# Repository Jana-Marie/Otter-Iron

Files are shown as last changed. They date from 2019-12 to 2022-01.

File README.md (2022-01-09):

# Otter-Iron

Replacement PCB for TS100, adds USB-C PD to every hacker's favourite tool!

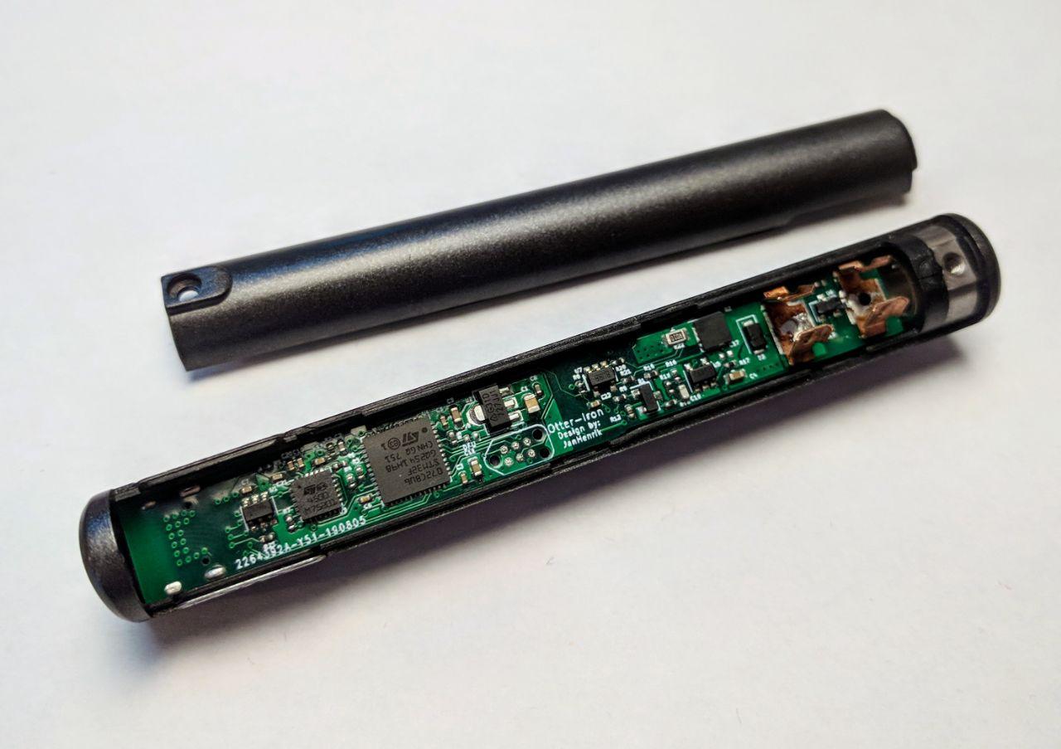
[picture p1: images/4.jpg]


Hardware v2.4 is released, changelog: you don't need to solder the tip connector anymore, software [v0.6](https://github.com/Jana-Marie/Otter-Iron/releases) is released!

Features:
 - You can solder!
 - Temperature can be adjusted via buttons
 - USB-PD requests highest voltage
 - Display shows set-temperature, temperature, input-voltage and power applied
 - Saves last set-temperature
 - Designed by an Otter *chirps* :3

## Ordering and assembly instructions

The BOM can be found at [KiCAD/Otter-Iron/production/kitspace_bom.csv](./KiCAD/Otter-Iron/production/kitspace_bom.csv). Most parts are generic parts, which can be ordered and assembled regularly. However, the display and tip-holders need special attention. The PCB has to be ordered with a thickness of 1mm (1.6mm works too, but 1mm has a better fit).

### Known hardware issues/notes

 * **Note: C19 and C20 changed from 100nF to 1µF in the last revision, please make sure to populate 1µF!**
 * Please add a pullup to the displays reset if the display does not work. See image below:

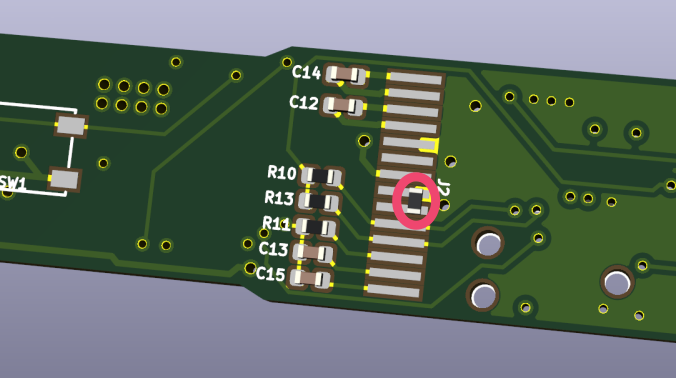
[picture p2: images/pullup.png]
 

### Tip-Holders / mechanical parts

The original tip-holders are custom made thus it is not possible to buy them, if you already have a TS100 it is highly recommended to recycle those. They can be unscrewed, cut to size and soldered/screwed onto the Otter-Iron. This is the preferred option!

If you don't own a TS100 you can buy one from miniware (price ranges from 35$ to 45$) and harvest the parts (as well as the casing and tip!).

You can also buy the littlefuse fuseholders mentioned in the BOM. Those however have a very bad fit, you have to bend them and add a little solder notch, otherwise you may destroy your tips. In addition to this solution you also need to buy a spare case+tip which is ~25-35$, this is the least preferred option.

### Display

The display can be bought from ~~[LCSC](https://lcsc.com/product-detail/OLED-Displays-Modules_UG-Univision-Semicon-UG-9616TSWCG02_C88335.html)~~ **note: Do not buy displays from LCSC, they seem to be faulty!** or [Aliexpress](https://de.aliexpress.com/item/32808645444.html), I haven't found it at Mouser yet ([Maybe its this display?](https://www.mouser.de/ProductDetail/ELECTRONIC-ASSEMBLY/EA-W096016-XALW?qs=f9yNj16SXrJLTMk24BHqcA%3D%3D)). It is the last part to be assembled, it is soldered on the back of the PCB facing the PCB and the tip-end.

## Flashing

To flash the Otter-Iron short the DFU-jumper shown in the image below while plugging it into your computer. This will put the iron into DFU mode allowing you to flash it via DFU/USB.

If you already have ad firmware >= v0.2 flashed, you can press both buttons while plugging in to enter DFU mode.

Run this command to flash the downloaded binary.

    $ dfu-util -a 0 -s 0x08000000:leave -D firmware.bin

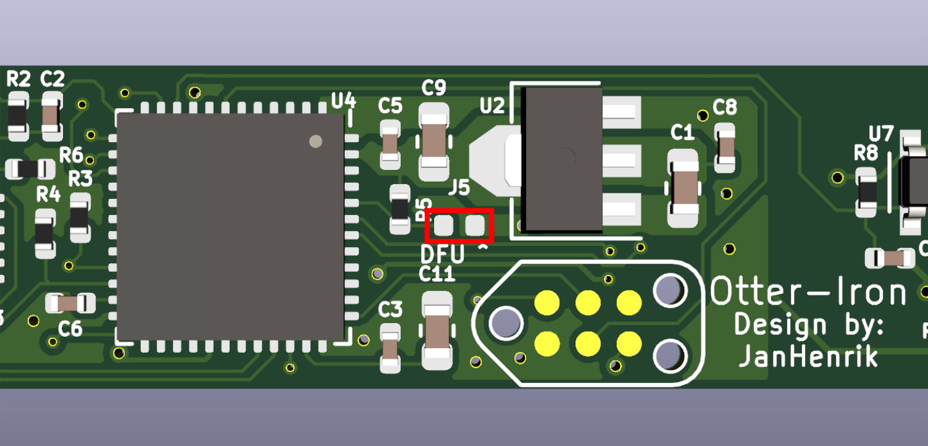
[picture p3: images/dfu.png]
dfu


## Video

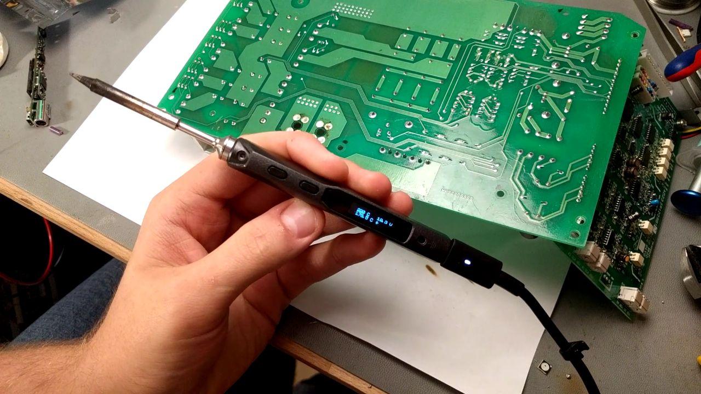
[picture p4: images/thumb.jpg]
Video (https://twitter.com/_Jana_Marie/status/1208867279540232192)


## Images

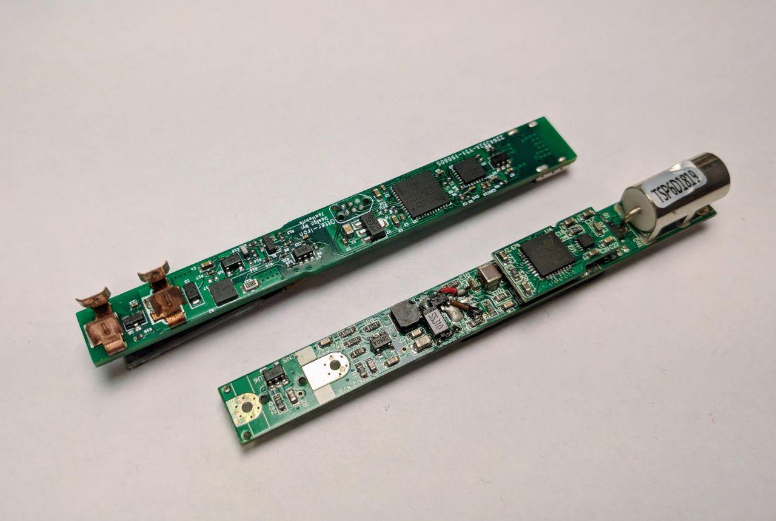
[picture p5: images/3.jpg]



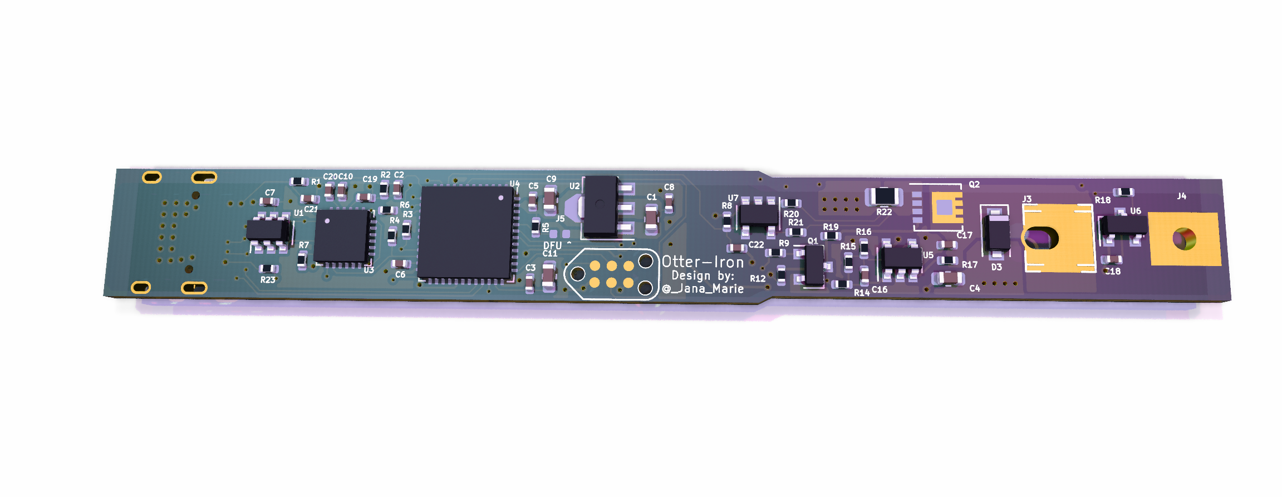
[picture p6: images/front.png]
Front

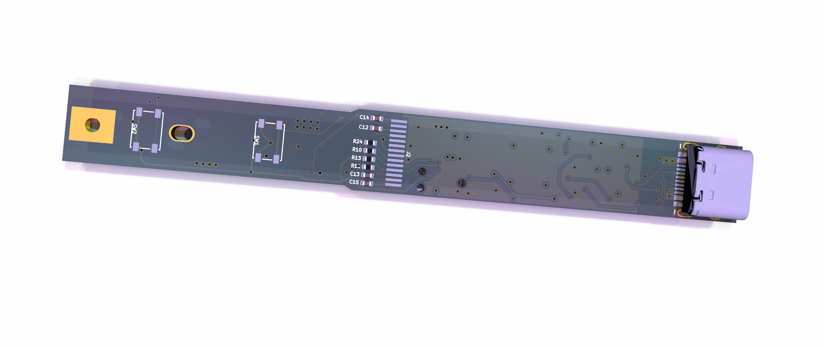
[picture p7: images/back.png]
Back


## Todo software

 - [x] Write a better regulation
 - [x] Current measurement
 - [x] Store last setpoint
 - [x] Better Fonts/UI
 - [x] PD-Profile cycling

## Todo Hardware

Todo next hardware revision:
 - [ ] Add barrel jack
 - [ ] Add grounding solution
 - [x] Fix Tag-Connect [see #4](https://github.com/Jana-Marie/Otter-Iron/issues/4)
 - [x] Optimize display-connector
 - [x] Add display reset pullup
 - [ ] Add display reset line
 - [ ] Add inrush current protection

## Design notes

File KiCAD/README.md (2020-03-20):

# Folder structure

## Otter-Iron

Replacement PCB for the TS100.



## Otter-Iron_Devkit

Small devboard based on the Otter-Iron for different tips (e.g. Weller RT, JBC C245)

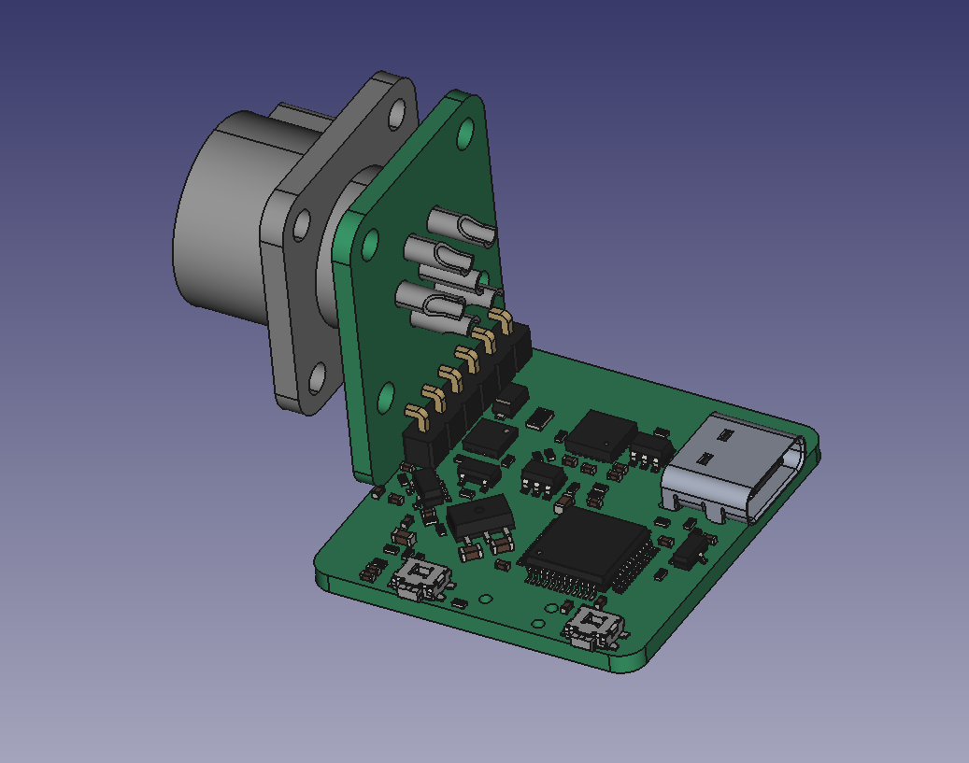
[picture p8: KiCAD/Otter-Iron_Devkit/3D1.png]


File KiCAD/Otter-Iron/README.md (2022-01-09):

[BOM](KiCAD/production/kitspace_bom.csv)

[Gerber](KiCAD/production/TS100CV2.3.zip)

[Kitspace](https://kitspace.org/boards/github.com/jana-marie/otter-iron/)

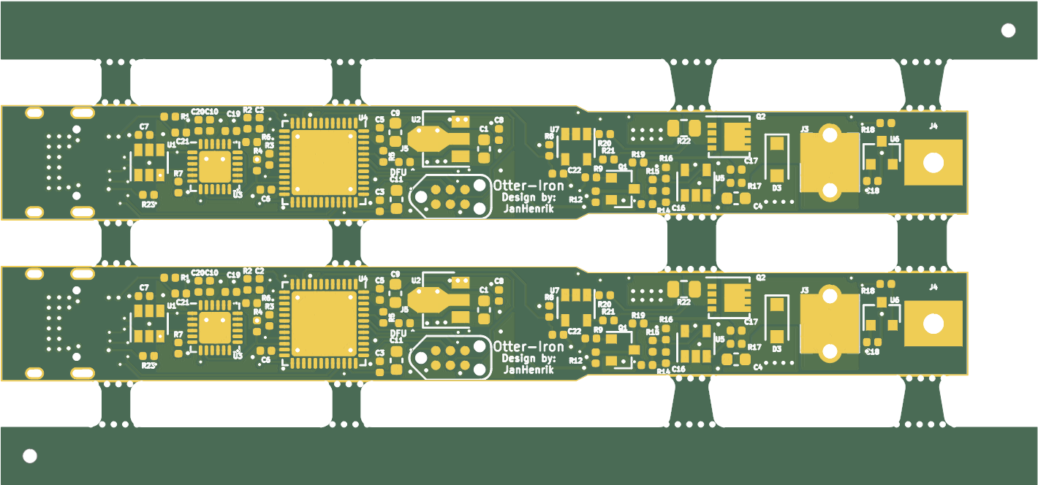
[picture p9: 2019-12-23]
KiCAD/Otter-Iron/production/v2.3_Combined_Top.png

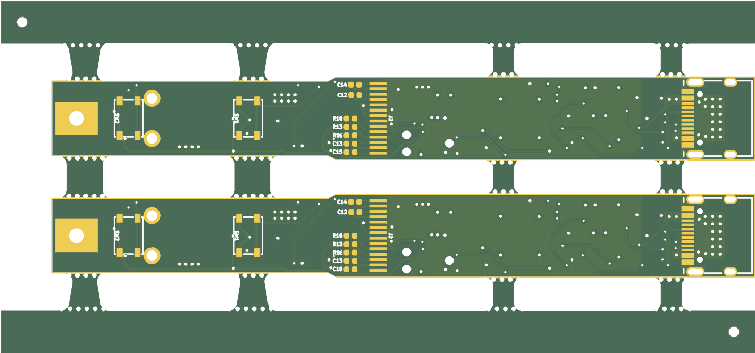
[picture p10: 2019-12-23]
KiCAD/Otter-Iron/production/v2.3_Combined_Bottom.png

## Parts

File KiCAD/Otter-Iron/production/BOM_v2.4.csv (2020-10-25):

Comment | Designator | Quantity | Footprint | LCSC | LCSC Part type | Mouser | Farnell
1μF 25V | C15,C13,C14,C12,C20,C19 | 6 | Capacitor_SMD:C_0402_1005Metric | C52923 | smt
18p | C16 | 1 | Capacitor_SMD:C_0402_1005Metric | C1549 | smt
DNP | C17 | 1 | Capacitor_SMD:C_0402_1005Metric | DNP | dnp
0.1μF | C3,C5,C7,C8,C10,C2,C18,C6,C21,C22 | 10 | Capacitor_SMD:C_0402_1005Metric | C1525 | smt
1μF 25V | C9,C1,C4,C11 | 4 | Capacitor_SMD:C_0603_1608Metric | C15849 | smt
B140-E3 | D3 | 1 | Diode_SMD:D_SOD-123F | C64891 | ext
USB_C_Receptacle_USB2.0 | J1 | 1 | otter:USB-C 16Pin | C319148 | lcsc
OLED_96x16 | J2 | 1 | otter:0.69OLED
A | J3 | 1 | otter:Keystone_3621 |  |  | 534-3621
B | J4 | 1 | otter:Keystone_3622 |  |  | 534-3622
DNP | J5 | 1 | Resistor_SMD:R_0402_1005Metric | DNP | dnp
SS8050 | Q1 | 1 | Package_TO_SOT_SMD:SOT-23 | C2150 | smt
DMP3017SFG | Q2 | 1 | otter:Diodes_PowerDI3333-8 | C461072 | lcsc
560k | R1,R11 | 2 | Resistor_SMD:R_0402_1005Metric | C132339 | ext
750k | R15 | 1 | Resistor_SMD:R_0402_1005Metric | C122545 | ext
20 | R19 | 1 | Resistor_SMD:R_0402_1005Metric | C25089 | ext
100k | R2,R17 | 2 | Resistor_SMD:R_0402_1005Metric | C25741 | smt
33 | R20,R21 | 2 | Resistor_SMD:R_0402_1005Metric | C25105 | smt
10m | R22 | 1 | Resistor_SMD:R_0805_2012Metric | C50732 | ext
2k37 | R5,R3,R4,R6,R12,R9,R10,R13,R16,R14,R18,R7,R8,R23 | 14 | Resistor_SMD:R_0402_1005Metric | C25881 | ext
key1 | SW1 | 1 | Button_Switch_SMD:SW_SPST_PTS810 | C92589 | lcsc
key2 | SW2 | 1 | Button_Switch_SMD:SW_SPST_PTS810 | C92589 | lcsc
USBLC6-4SC6 | U1 | 1 | Package_TO_SOT_SMD:SOT-23-6 | C111212 | ext |  | 1295311
AP2204R-3.3 | U2 | 1 | Package_TO_SOT_SMD:SOT-89-3 | C156303 | ext
STUSB4500QTR | U3 | 1 | Package_DFN_QFN:QFN-24-1EP_4x4mm_P0.5mm_EP2.7x2.7mm |  |  | 511-STUSB4500QTR | 2980889
STM32F072CBUx | U4 | 1 | Package_DFN_QFN:QFN-48-1EP_7x7mm_P0.5mm_EP5.6x5.6mm | C92504 | ext
OPA340NA | U5 | 1 | Package_TO_SOT_SMD:SOT-23-5 | C73479 | ext
MCP9700AT-ETT | U6 | 1 | Package_TO_SOT_SMD:SOT-23 |  |  | 579-MCP9700AT-E/TT | 1605577
SI8540 | U7 | 1 | Package_TO_SOT_SMD:SOT-23-5 |  |  | 634-SI8540-B-FWR | SI8540

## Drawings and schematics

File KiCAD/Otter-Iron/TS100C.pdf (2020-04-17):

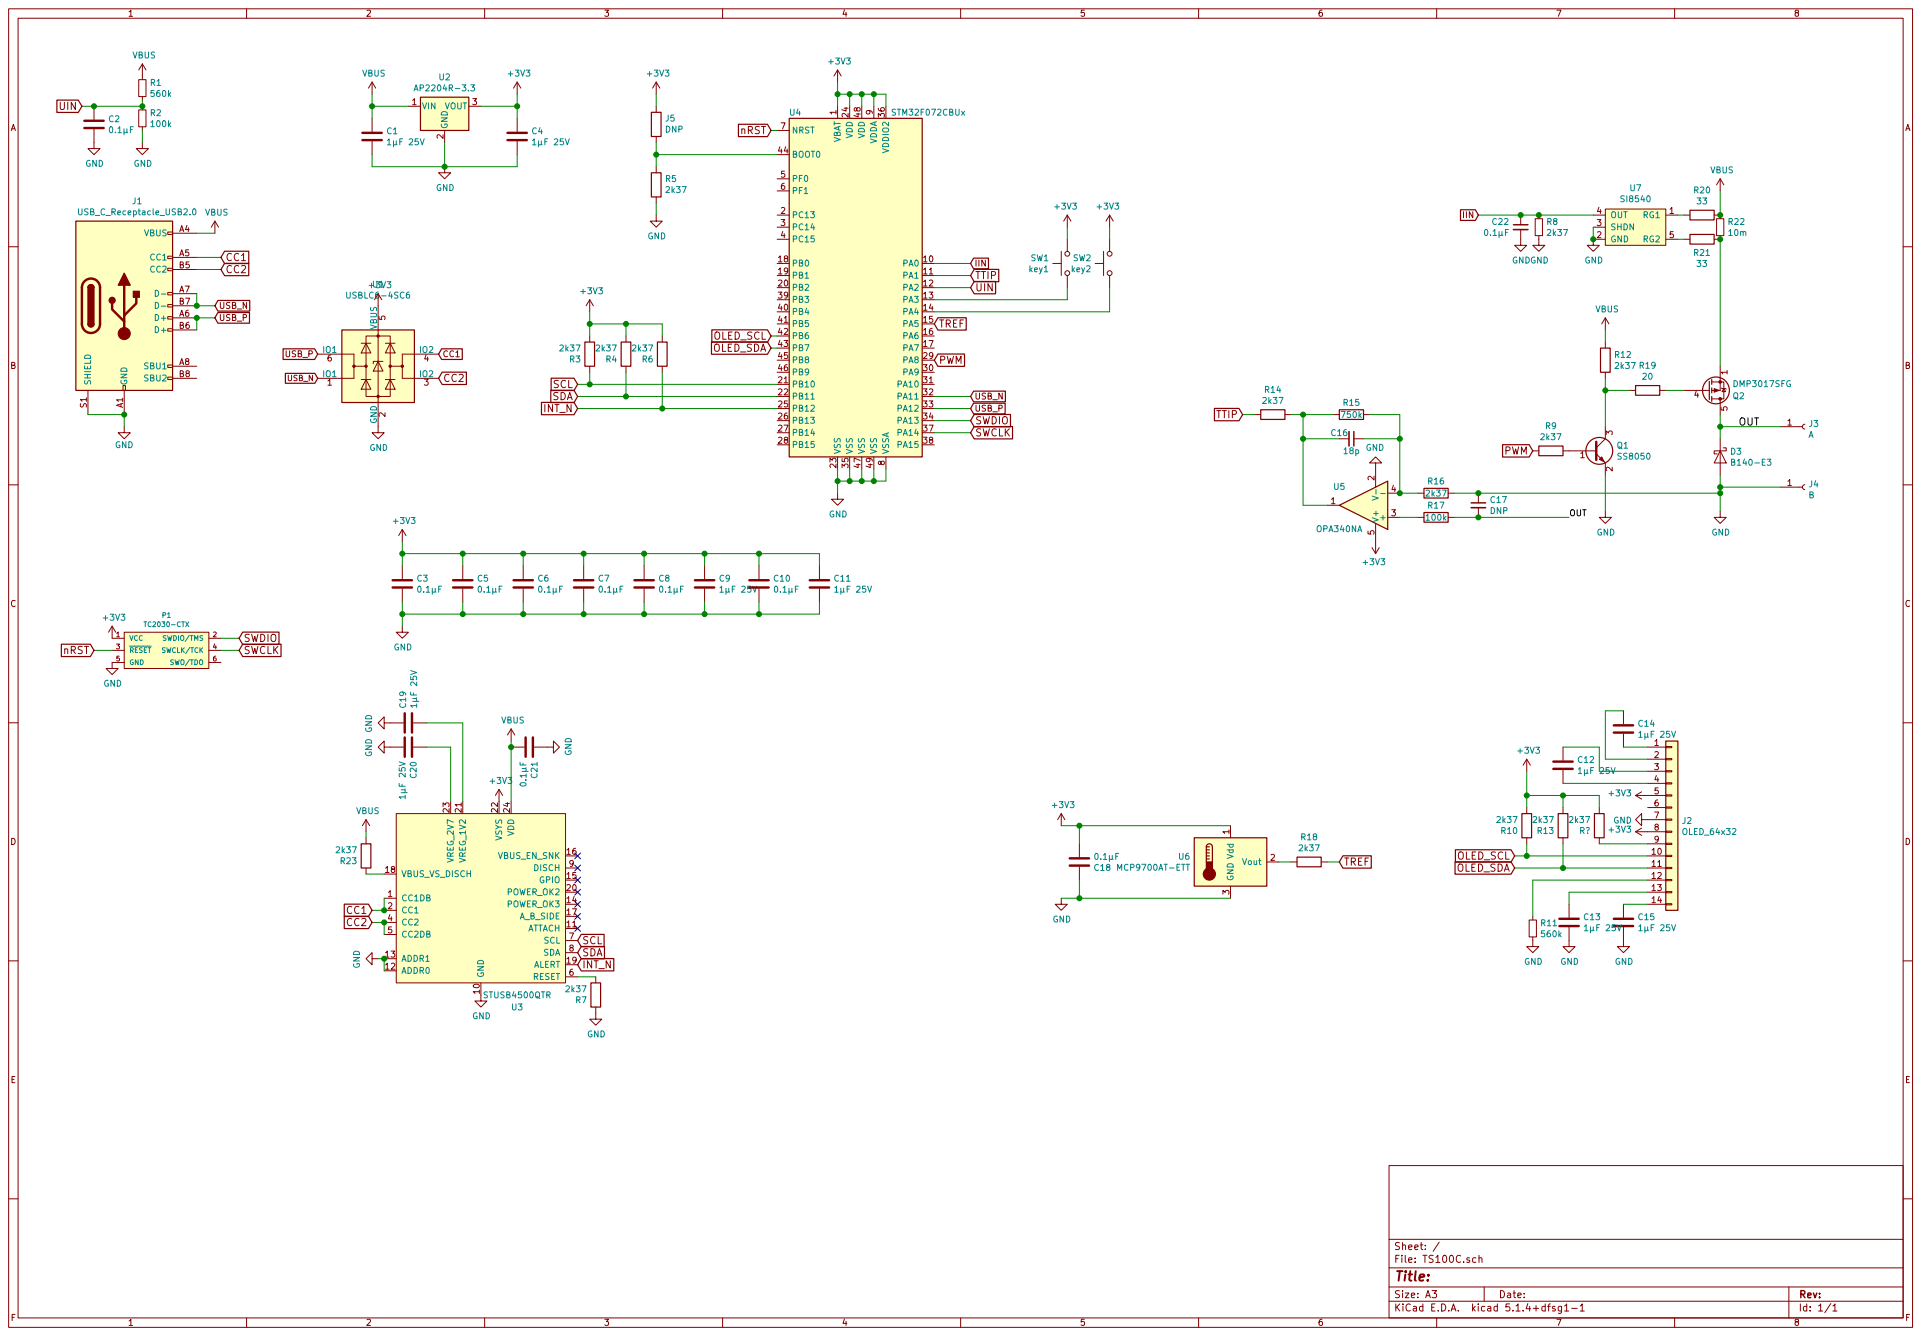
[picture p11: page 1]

9 VDDIO2 36 VSS 23 VSS 35 VSS 47 VSS 49 VSSA

Id: 1/1 Title: File: TS100C.sch Sheet: /

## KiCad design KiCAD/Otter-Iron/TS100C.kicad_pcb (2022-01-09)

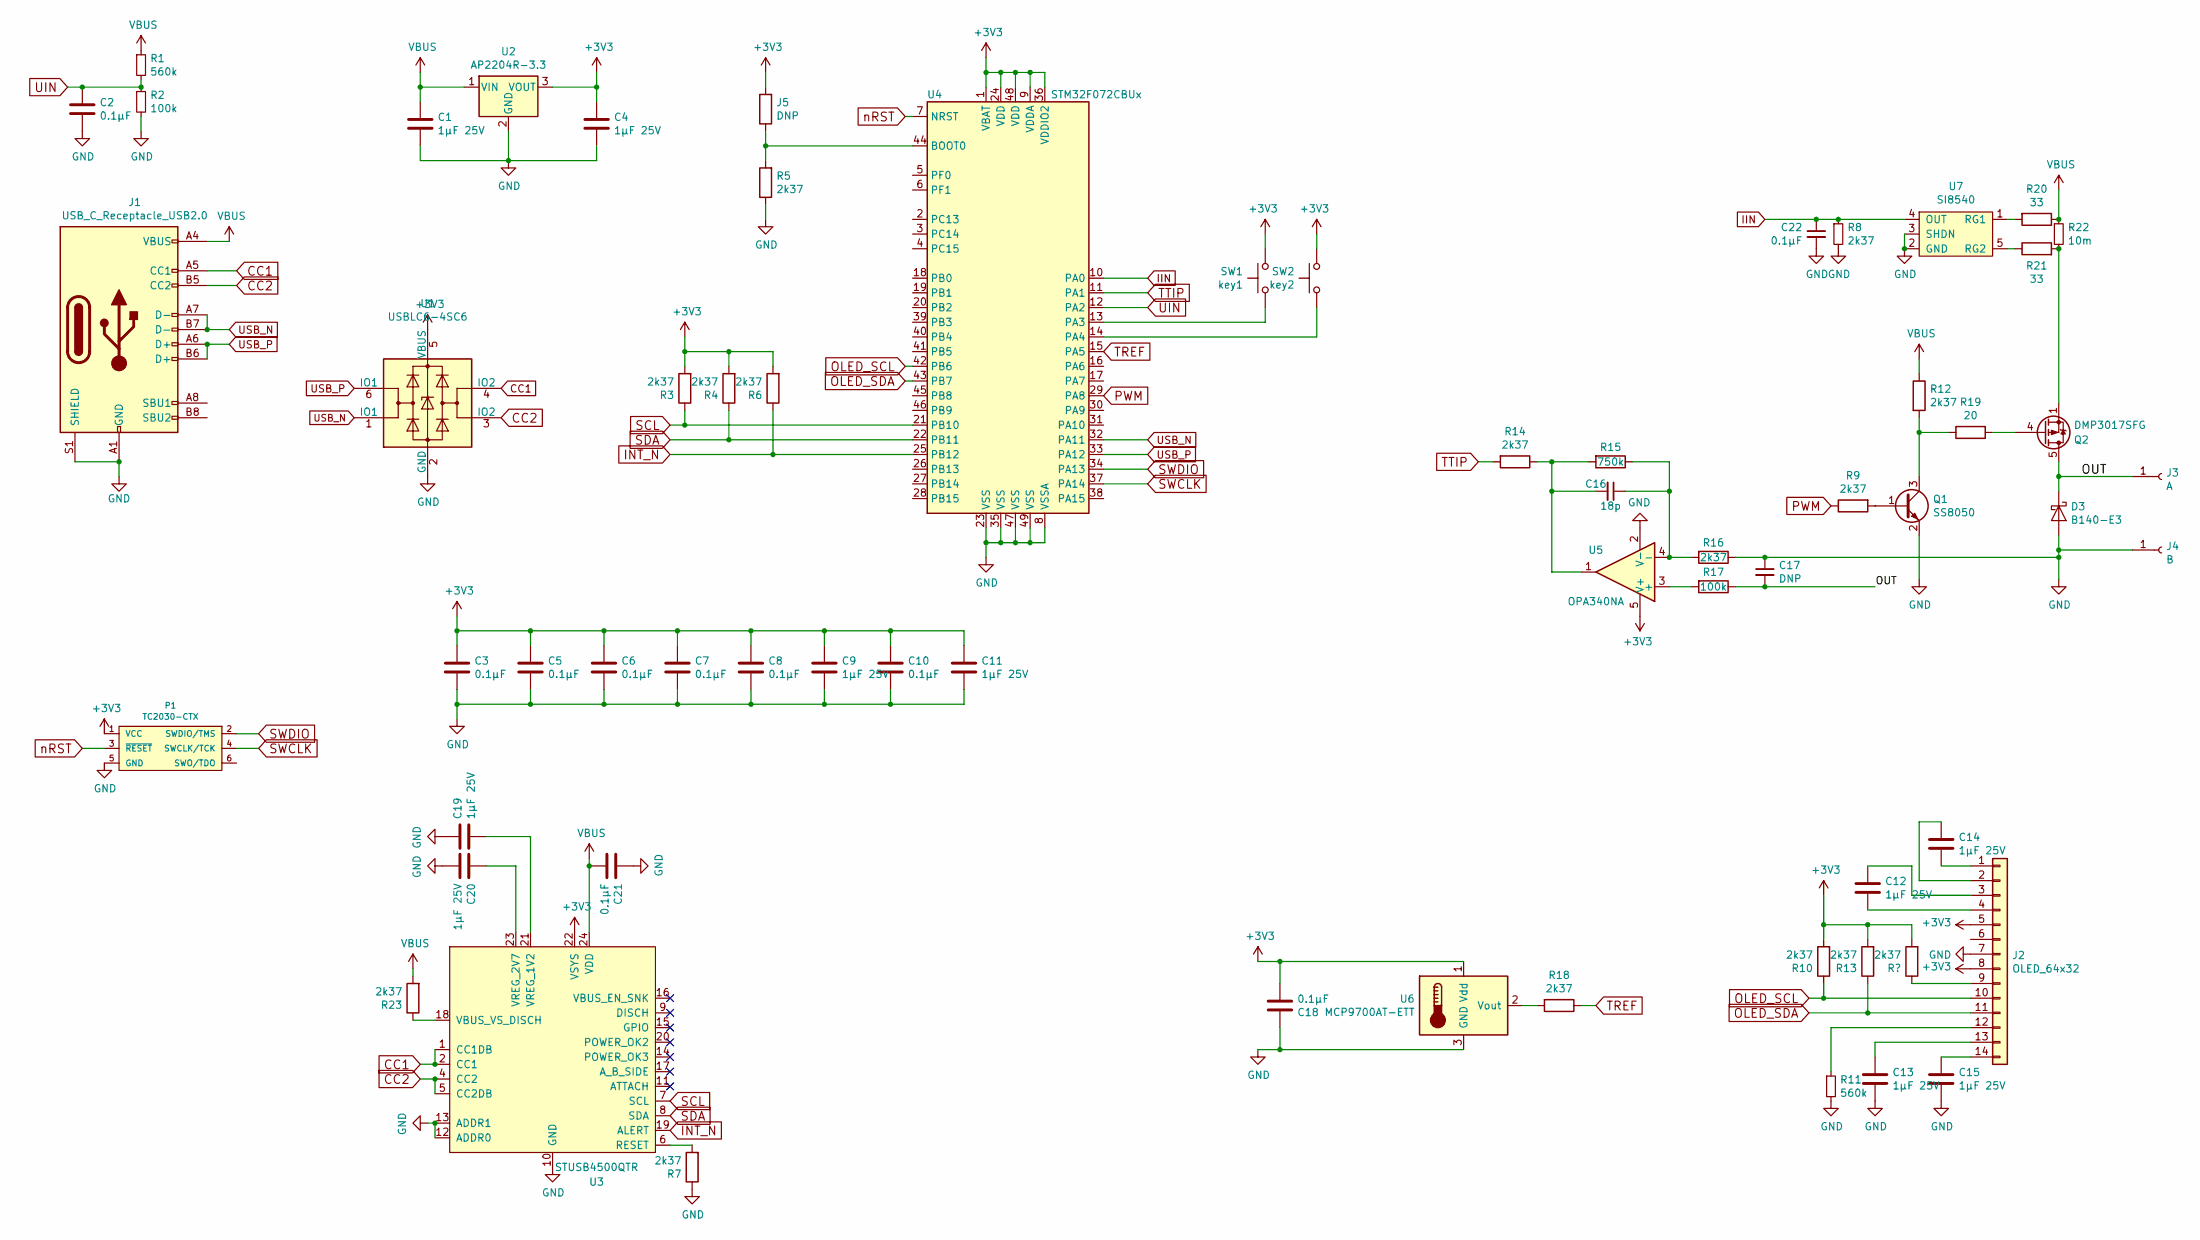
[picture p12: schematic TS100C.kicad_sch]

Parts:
C1, C4, C9, C11: 1μF 25V; C_0603_1608Metric
C2, C3, C5, C6, C7, C8, C10, C18, C21, C22: 0.1μF; C_0402_1005Metric
C12, C13, C14, C15, C19, C20: 1μF 25V; C_0402_1005Metric
C16: 18p; C_0402_1005Metric
C17: DNP; C_0402_1005Metric
D3: B140-E3; D_SOD-123F
J1: USB_C_Receptacle_USB2.0; USB-C 16Pin
J2: OLED_64x32; 0.69OLED
J3: A; Keystone_3621
J4: B; 3622TR
J5: DNP; R_0402_1005Metric
P1: TC2030-CTX; TC2030-NL_SMALL
Q1: SS8050; SOT-23
Q2: DMP3017SFG; Diodes_PowerDI3333-8
R1, R11: 560k; R_0402_1005Metric
R2, R17: 100k; R_0402_1005Metric
R3, R4, R5, R6, R7, R8, R9, R10, R12, R13, R14, R16, R18, R23: 2k37; R_0402_1005Metric
R15: 750k; R_0402_1005Metric
R19: 20; R_0402_1005Metric
R20, R21: 33; R_0402_1005Metric
R22: 10m; R_0805_2012Metric
SW1: key1; SW_SPST_PTS810
SW2: key2; SW_SPST_PTS810
U1: USBLC6-4SC6; SOT-23-6
U2: AP2204R-3.3; SOT-89-3
U3: STUSB4500QTR; QFN-24-1EP_4x4mm_P0.5mm_EP2.7x2.7mm
U4: STM32F072CBUx; QFN-48-1EP_7x7mm_P0.5mm_EP5.6x5.6mm
U5: OPA340NA; SOT-23-5
U6: MCP9700AT-ETT; SOT-23
U7: SI8540; SOT-23-5

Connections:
+3V3: C3.1, C4.1, C5.1, C6.1, C7.1, C8.1, C9.1, C10.1, C11.1, C18.1, J2.5, J2.8, J5.2, P1.1 (VCC), R3.2, R4.2, R6.2, R10.2, R13.2, SW1.1, SW2.1, U1.5 (VBUS), U2.3 (VOUT), U3.22 (VSYS), U4.1 (VBAT), U4.9 (VDDA), U4.24 (VDD), U4.36 (VDDIO2), U4.48 (VDD), U5.5 (V+), U6.1 (Vdd); also elsewhere on the board
/OUT: C17.2, D3.1 (K), J3.1, Q2.5 (D), R17.1
CC1: J1.A5 (CC1), U1.4 (IO2), U3.1 (CC1DB), U3.2 (CC1)
CC2: J1.B5 (CC2), U1.3 (IO2), U3.4 (CC2), U3.5 (CC2DB)
GND: C1.2, C2.2, C3.2, C4.2, C5.2, C6.2, C7.2, C8.2, C9.2, C10.2, C11.2, C13.2, C15.2, C17.1, C18.2, C19.1, C20.2, C21.1, C22.2, D3.2 (A), J1.A1 (GND), J1.A12 (GND), J1.B1 (GND), J1.B12 (GND), J1.S1 (SHIELD), J2.7, J4.1, P1.5 (GND), Q1.2 (E), R2.2, R5.1, R7.1, R8.2, R11.2, R16.1, U1.2 (GND), U2.2 (GND), U3.10 (GND), U3.12 (ADDR0), U3.13 (ADDR1), U3.25 (GND), U4.8 (VSSA), U4.23 (VSS), U4.35 (VSS), U4.47 (VSS), U4.49 (VSS), U5.2 (V-), U6.3 (GND), U7.2 (GND), U7.3 (SHDN)
IIN: C22.1, R8.1, U4.10 (PA0), U7.4 (OUT)
INT_N: R6.1, U3.19 (ALERT), U4.25 (PB12)
unnamed: C12.1, J2.3
unnamed: C12.2, J2.4
unnamed: C13.1, J2.13
unnamed: C14.1, J2.2
unnamed: C14.2, J2.1
unnamed: C15.1, J2.14
unnamed: C16.1, R15.1, R16.2, U5.4 (-)
unnamed: C16.2, R14.1, R15.2, U5.1
unnamed: C19.2, U3.21 (VREG_1V2)
unnamed: C20.1, U3.23 (VREG_2V7)
unnamed 20: J2.9; also elsewhere on the board
unnamed: J2.12, R11.1
unnamed: J5.1, R5.2, U4.44 (BOOT0)
unnamed: Q1.1 (B), R9.2
unnamed: Q1.3 (C), R12.2, R19.1
unnamed: Q2.1 (S), Q2.2 (S), Q2.3 (S), R21.2, R22.2
unnamed: Q2.4 (G), R19.2
unnamed: R7.2, U3.6 (RESET)
unnamed: R17.2, U5.3 (+)
unnamed: R18.2, U6.2 (Vout)
unnamed: R20.2, U7.1 (RG1)
unnamed: R21.1, U7.5 (RG2)
unnamed: R23.1, U3.18 (VBUS_VS_DISCH)
unnamed: SW1.2, U4.13 (PA3)
unnamed: SW2.2, U4.14 (PA4)
OLED_SCL: J2.10, R10.1, U4.42 (PB6)
OLED_SDA: J2.11, R13.1, U4.43 (PB7)
PWM: R9.1, U4.29 (PA8)
SCL: R3.1, U3.7 (SCL), U4.21 (PB10)
SDA: R4.1, U3.8 (SDA), U4.22 (PB11)
SWCLK: P1.4 (SWCLK/TCK), U4.37 (PA14)
SWDIO: P1.2 (SWDIO/TMS), U4.34 (PA13)
TREF: R18.1, U4.15 (PA5)
TTIP: R14.2, U4.11 (PA1)
UIN: C2.1, R1.2, R2.1, U4.12 (PA2)
USB_N: J1.A7 (D-), J1.B7 (D-), U1.1 (IO1), U4.32 (PA11)
USB_P: J1.A6 (D+), J1.B6 (D+), U1.6 (IO1), U4.33 (PA12)
VBUS: C1.1, C21.2, J1.A4 (VBUS), J1.A9 (VBUS), J1.B4 (VBUS), J1.B9 (VBUS), R1.1, R12.1, R20.1, R22.1, R23.2, U2.1 (VIN), U3.24 (VDD)
nRST: P1.3 (~RESET), U4.7 (NRST)

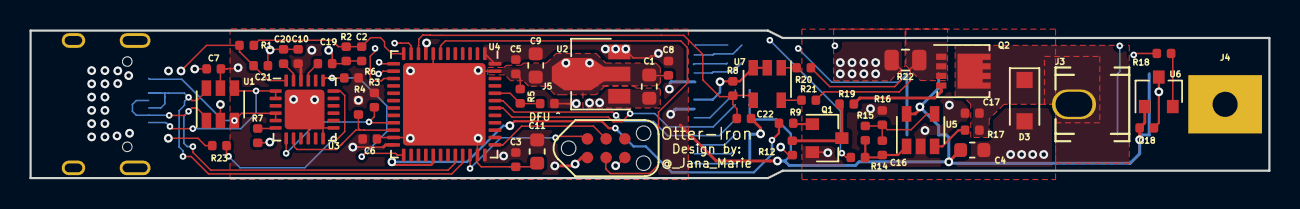
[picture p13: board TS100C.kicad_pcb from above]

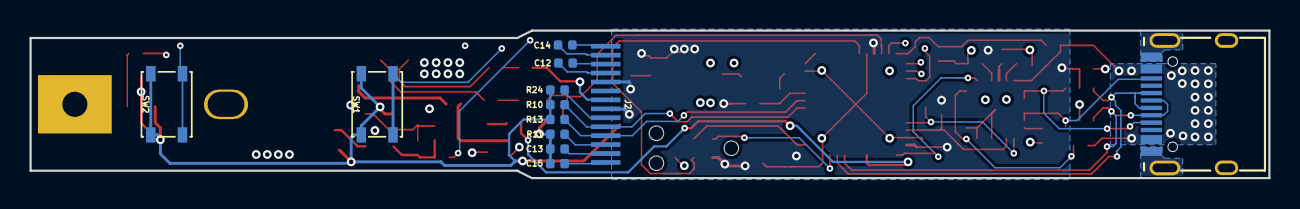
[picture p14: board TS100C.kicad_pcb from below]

Board: 4 copper layers, 84.0 x 10.0 mm, 64 parts (12 on the bottom side), 46 nets.

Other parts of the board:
R24: 2k37; R_0402_1005Metric

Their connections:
+3V3: R24.2; also elsewhere on the board
unnamed 20: R24.1; also elsewhere on the board

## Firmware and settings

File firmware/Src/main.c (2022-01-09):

/*
 * Otter-Iron  -  Stm32f072 based soldering iron.
 * Copyright (C) 2020 Jan Henrik Hemsing
 *
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
 * You should have received a copy of the GNU General Public License along with
 * this program.  If not, see <http://www.gnu.org/licenses/>.
 */

#include "main.h"
#include <math.h>
#include "font.h"
#include "stusb4500.h"

// Enable serial printing via CDC, quite buggy
//#define ENABLESERIAL
// Enable Current display, shows up after a few millisecconds instead of temp-target
//#define DISPLAYCURRENT
// Enable Current limiting
//#define CURRENTLIM
// Enable check of USB PD profile capable before beforing iron
#define CHECKUSBPD

#define FILT(a, b, c) ((a) * (c) + (b) * ((1.0f) - (c)))
#define CLAMP(x, low, high) (((x) > (high)) ? (high) : (((x) < (low)) ? (low) : (x)))

#define TTIP_AVG_FILTER 0.9f
#define DISP_AVG_FILTER 0.9f

#define MIN_DUTY 0
uint16_t MAX_DUTY = 3990;

#define MIN_VOLTAGE 15.0f
#define MIN_CURRENT 1.0f

ADC_HandleTypeDef hadc;
DMA_HandleTypeDef hdma_adc;

I2C_HandleTypeDef hi2c1;
I2C_HandleTypeDef hi2c2;

TIM_HandleTypeDef htim1;
TIM_HandleTypeDef htim3;

IWDG_HandleTypeDef hiwdg;

USBD_HandleTypeDef USBD_Device;

void SystemClock_Config(void);
static void MX_GPIO_Init(void);
static void MX_ADC_Init(void);
static void MX_DMA_Init(void);
static void MX_I2C1_Init(void);
static void MX_I2C2_Init(void);
static void MX_TIM1_Init(void);
static void TIM3_Init(void);
static void MX_IWDG_Init(void);

void reg(void);
void disp_init(void);
void refresh(void);
void clear_screen(void);
void set_screen(void);
void write_pixel(int16_t x, int16_t y, uint8_t color);
void draw_char(unsigned char  c, uint8_t x, uint8_t y, uint8_t brightness);
void draw_string(const unsigned char * str, uint8_t x, uint8_t y, uint8_t brightness);
void draw_v_line(int16_t x, int16_t y, uint16_t h, uint8_t color);
void USB_printfloat(float _buf);

struct status_t{
  float ttip;
  float ttipavg;
  float uin;
  float iin;
  float iinavg;
  float imax;
  float tref;
  uint8_t writeFlash;
  uint8_t button[2];
  float drawlineavg;
#ifdef DISPLAYCURRENT
  uint8_t timeout;
#endif
  uint8_t active;
  uint8_t pdo;
}s = {.writeFlash = 0, .imax = 1.1f};

struct reg_t{
  float target;
  float error;
  float errorprior;
  float ierror;
  float imax;
  float derror;
  int16_t duty;
  float cycletime;
  float Kp;
  float Ki;
  float Kd;
  float deadband;
}r = {.Kp = 0.3f,.Ki = 0.13f,.Kd = 0.3f,.cycletime = 0.1f,.imax=200.0f,.target=220.0f,.deadband=12.0f};

struct tipcal_t{
  float offset;
  float coefficient;
} tipcal = {.offset = 120, .coefficient = 92};

static uint16_t ADC_raw[4];

extern uint8_t UserTxBuffer[APP_TX_DATA_SIZE];/* Received Data over UART (CDC interface) are stored in this buffer */
uint32_t sendDataUSB;

const unsigned char* dfu_string = (unsigned char*) "dfu dfu dfu dfu";
const unsigned char* otter_string = (unsigned char*) "Otter-Iron";
const unsigned char* by_string = (unsigned char*) "by Jana Marie";

int main(void)
{
  HAL_Init();

  SystemClock_Config();

  MX_GPIO_Init();
  MX_DMA_Init();
  MX_ADC_Init();
  MX_I2C1_Init();
  MX_I2C2_Init();
  MX_TIM1_Init();
  TIM3_Init();

  // setup STUSB4500 PD requests before starting controller IT
  stusb_update_pdo(1, 5000, 500); // allows comms on standard 5 V
  // 30 W and 80 W - ensures iron is well behaved and enumerates PD profile before drawing it
  stusb_update_pdo(2, 15000, 1500);
  stusb_update_pdo(3, 20000, 2000);
  stusb_set_valid_pdo(3);

  HAL_Delay(50);
  disp_init();
  HAL_Delay(150);
  clear_screen();

  HAL_TIM_PWM_Start(&htim1, TIM_CHANNEL_1);
  HAL_TIM_OC_Start(&htim1, TIM_CHANNEL_4);

  HAL_ADC_Start_DMA(&hadc, (uint32_t *)ADC_raw, 4);

  // DFU bootloader
  if(HAL_GPIO_ReadPin(GPIOA,B1_Pin) && HAL_GPIO_ReadPin(GPIOA,B2_Pin)){
    draw_string(dfu_string, 1, 1 ,1);
    draw_string(dfu_string, 1, 8 ,1);
    refresh();
    HAL_Delay(40);
    *((unsigned long *)0x20003FF0) = 0xDEADBEEF;
    NVIC_SystemReset();
  } else {
    draw_string(otter_string, 15, 1 ,1);
    draw_string(by_string, 10, 9 ,1);
    refresh();
#ifdef ENABLESERIAL
    //start USB CDC
    USBD_Init(&USBD_Device, &VCP_Desc, 0);
    USBD_RegisterClass(&USBD_Device, &USBD_CDC);
    USBD_CDC_RegisterInterface(&USBD_Device, &USBD_CDC_fops);
    HAL_TIM_Base_Start_IT(&htim3);
    USBD_Start(&USBD_Device);
#endif
#ifdef DISPLAYCURRENT
      s.timeout = 20;
#endif
#ifdef CHECKUSBPD
    unsigned char line1[22];
    unsigned char line2[22];
    STUSB_GEN1S_RDO_REG_STATUS_RegTypeDef Nego_RDO;

      if (stusb_read_rdo(&Nego_RDO) == HAL_OK && Nego_RDO.b.Object_Pos != 0) {
        s.imax = (float) Nego_RDO.b.MaxCurrent / 100.0;
        s.pdo = Nego_RDO.b.Object_Pos;
      } else {
        stusb_update_pdo(2, 9000, 900);
        stusb_update_pdo(3, 12000, 1000);
        stusb_soft_reset();
        HAL_Delay(300);
        if (stusb_read_rdo(&Nego_RDO) == HAL_OK) {
          s.imax = (float) Nego_RDO.b.MaxCurrent / 100.0;
          s.pdo = Nego_RDO.b.Object_Pos;
        } else {
          s.pdo = 0;
        }
      }

    if (s.pdo > 0) {
      sprintf((char * restrict) line1, "PD %s %1d", s.pdo > 3 ? "Adjust" : "Profile", s.pdo);
      sprintf((char * restrict) line2, "%1d.%1d A %2d W", (uint16_t)s.imax,(uint16_t)((s.imax-(uint16_t)s.imax)*10.0f), (uint16_t) (ceil(s.uin) * s.imax));
    } else {
      sprintf((char * restrict) line1, "USB !USB-PD");
      sprintf((char * restrict) line2, "Iron Disabled");
    }
    clear_screen();
    draw_string(line1, 10, 1 ,1);
    draw_string(line2, 10, 9 ,1);
    refresh();
    HAL_Delay(1000);
#endif
  }

  HAL_Delay(1000);
  MX_IWDG_Init();

  r.target = *((uint16_t *) 0x0800e400);
  if(r.target > 400) r.target = 220;  //initial temp set

  while (1)
  {
    HAL_Delay(50);

    //UI
    s.button[0] = HAL_GPIO_ReadPin(GPIOA,B1_Pin);
    s.button[1] = HAL_GPIO_ReadPin(GPIOA,B2_Pin) | HAL_GPIO_ReadPin(GPIOC, B1_1_Pin);

    if(s.button[0] == 1){
      r.target -= 5;
      s.writeFlash = 1;
      HAL_Delay(40);
    }

    if(s.button[1] == 1){
      r.target += 5;
      s.writeFlash = 1;
      HAL_Delay(40);
    }

    r.target = CLAMP(r.target, 20, 400);

    if(s.writeFlash == 1){
      HAL_FLASH_Unlock();
      FLASH->CR |= FLASH_CR_PER;
      FLASH->AR = 0x0800e400;
      FLASH->CR |= FLASH_CR_STRT;
      while ((FLASH->SR & FLASH_SR_BSY) != 0){}
      if ((FLASH->SR & FLASH_SR_EOP) != 0){
        FLASH->SR |= FLASH_SR_EOP;
        FLASH->CR &= ~FLASH_CR_PER;
        HAL_FLASH_Program(FLASH_TYPEPROGRAM_HALFWORD, 0x0800e400, (uint16_t)r.target);
        HAL_FLASH_Lock();
        s.writeFlash = 0;
      }
      #ifdef DISPLAYCURRENT
            s.timeout = 12;
      #endif
    }

#ifdef ENABLESERIAL
    // send temperature via USB CDC
    USB_printfloat(r.error);
#endif

    //super shitty display code
    unsigned char str1[14] = "          ";
    unsigned char str2[14] = "          ";
    unsigned char str3[14] = "          ";
    unsigned char str4[14] = "          ";
    sprintf((char * restrict) str1, "%d C   ", (uint16_t)r.target);
    sprintf((char * restrict) str2, "%d.%d C", (uint16_t)s.ttipavg,(uint16_t)((s.ttipavg-(uint16_t)s.ttipavg)*10.0f));
    sprintf((char * restrict) str3, "%d.%d V", (uint16_t)s.uin,(uint16_t)((s.uin-(uint16_t)s.uin)*10.0f));
    sprintf((char * restrict) str4, "%d.%d A", (uint16_t)s.iin,(uint16_t)((s.iin-(uint16_t)s.iin)*10.0f));

    clear_screen();
    draw_string(str1, 10, 1 ,1);
    draw_string(str2, 10, 9 ,1);
    draw_string(str3, 60, 1 ,1);
#ifdef DISPLAYCURRENT
    if(s.timeout == 0){
      draw_string(str4, 10, 1 ,1);
    } else {
      s.timeout--;
    }
#endif
    s.iinavg = (s.iinavg * DISP_AVG_FILTER) + (s.iin*(1.0-DISP_AVG_FILTER));

    if (s.active) {
      s.drawlineavg = (s.drawlineavg * DISP_AVG_FILTER) + (CLAMP(r.error*3.0f,0,30)*(1.0-DISP_AVG_FILTER));
      for(uint16_t i = 0; i <= (int)s.drawlineavg; i++){
        draw_v_line(60+i, 8, 8, 1);
      }
    } else {
      draw_string((const unsigned char*) ((s.pdo > 0) ? "!ACTV" : "!PWRD"), 60, 9, 1);
    }

    refresh();
    HAL_IWDG_Refresh(&hiwdg);
  }
}

uint8_t check_usbpd(void) {
 #ifdef CHECKUSBPD
  return (s.uin >= MIN_VOLTAGE && s.imax >= MIN_CURRENT);
 #else
  return 1;
 #endif
}

// Main PID+two-way controller and ADC readout
void reg(void) {
  s.tref = ((((float)ADC_raw[3]/4095.0)*3.3)-0.5)/0.01;
  s.ttip = ((ADC_raw[1]-tipcal.offset)*tipcal.coefficient)/1000+s.tref;
  s.uin = ((ADC_raw[2]/4095.0)*3.3)*6.6;
  s.iin = FILT(s.iin, ((ADC_raw[0]/4095.0)*3.3*1.659)/(0.01*(2370/33)), TTIP_AVG_FILTER);

  s.ttipavg = FILT(s.ttipavg, s.ttip, TTIP_AVG_FILTER);

  // Check if within deadband, decide on two-way or PID control
  if(s.ttipavg >= r.target-r.deadband && s.ttipavg <= r.target+r.deadband){
    r.error = r.target - s.ttipavg;
    r.ierror = r.ierror + (r.error*r.cycletime);
    r.ierror = CLAMP(r.ierror,-r.imax,r.imax);
    r.derror = (r.error - r.errorprior)/r.cycletime;
    r.duty = (r.Kp*r.error + r.Ki*r.ierror + r.Kd*r.derror)*MAX_DUTY;
    r.errorprior = r.error;
  } else {
    if(s.ttipavg <= r.target){
      r.duty = MAX_DUTY;
      r.error = 12.0;
    } else {
      r.duty = MIN_DUTY;
      r.error = 0.0;
    }
  }

  r.duty = CLAMP(r.duty, MIN_DUTY, MAX_DUTY); // Clamp to duty cycle

#ifdef CURRENTLIM
  if(s.iin > s.imax && r.duty > 100){ // Current limiting
    MAX_DUTY = r.duty - 1;
    r.duty -= 100;
  } else {
    MAX_DUTY++;
    if(MAX_DUTY >= 3990) MAX_DUTY = 3990;
  }
#endif

  __HAL_TIM_SET_COMPARE(&htim1, TIM_CHANNEL_1, r.duty);
  __HAL_TIM_SET_COMPARE(&htim1, TIM_CHANNEL_4, 4050);
}

void HAL_TIM_PeriodElapsedCallback(TIM_HandleTypeDef *htim) //send USB cdc data
{
  if(sendDataUSB) // WIP need to fix this, should me timer based only
  {
    sendDataUSB = 0;

    USBD_CDC_SetTxBuffer(&USBD_Device, (uint8_t*)&UserTxBuffer[0], APP_TX_DATA_SIZE);
    USBD_CDC_TransmitPacket(&USBD_Device);
  }
}

#ifdef ENABLESERIAL
void USB_printfloat(float _buf){
  memset(UserTxBuffer, 0, APP_TX_DATA_SIZE);
  sprintf(UserTxBuffer, "%d.%d \r\n", (uint16_t)_buf,(uint16_t)((_buf-(uint16_t)_buf)*10.0f));
  sendDataUSB = 1;
}
#endif


// init code sequence by Ralim, thanks alot!
#define DEVICEADDR_OLED   (0x3c<<1)
#define OLED_WIDTH        96
#define FRAMEBUFFER_START 17
uint8_t screenBuffer[16 + (OLED_WIDTH * 2) + 10];  // The data buffer
const uint8_t REFRESH_COMMANDS[17] = { 0x80, 0xAF, 0x80, 0x21, 0x80, 0x20, 0x80, 0x7F, 0x80, 0xC0, 0x80, 0x22, 0x80, 0x00, 0x80, 0x01, 0x40 };
uint8_t OLED_Setup_Array[] = {
0x80, 0xAE, /*Display off*/
0x80, 0xD5, /*Set display clock divide ratio / osc freq*/
0x80, 0x52, /*Divide ratios*/
0x80, 0xA8, /*Set Multiplex Ratio*/
0x80, 0x0F, /*16 == max brightness,39==dimmest*/
0x80, 0xC0, /*Set COM Scan direction*/
0x80, 0xD3, /*Set vertical Display offset*/
0x80, 0x00, /*0 Offset*/
0x80, 0x40, /*Set Display start line to 0*/
0x80, 0xA0, /*Set Segment remap to normal*/
0x80, 0x8D, /*Charge Pump*/
0x80, 0x14, /*Charge Pump settings*/
0x80, 0xDA, /*Set VCOM Pins hardware config*/
0x80, 0x02, /*Combination 2*/
0x80, 0x81, /*Contrast*/
0x80, 0x33, /*^51*/
0x80, 0xD9, /*Set pre-charge period*/
0x80, 0xF1, /*Pre charge period*/
0x80, 0xDB, /*Adjust VCOMH regulator ouput*/
0x80, 0x30, /*VCOM level*/
0x80, 0xA4, /*Enable the display GDDR*/
0x80, 0XA6, /*Normal display*/
0x80, 0x20, /*Memory Mode*/
0x80, 0x00, /*Wrap memory*/
0x80, 0xAF /*Display on*/
};
//not Ralim anymore
void disp_init(void) {
  memcpy(&screenBuffer[0], &REFRESH_COMMANDS[0], sizeof(REFRESH_COMMANDS));
  uint16_t _cnt = 0;
  while (HAL_I2C_GetState(&hi2c1) != HAL_I2C_STATE_READY) if (_cnt++ > 10000) break;
  HAL_I2C_Master_Transmit(&hi2c1,DEVICEADDR_OLED, &OLED_Setup_Array[0],sizeof(OLED_Setup_Array),1000);
}

void refresh(void) {
  uint16_t _cnt = 0;
  while (HAL_I2C_GetState(&hi2c1) != HAL_I2C_STATE_READY) if (_cnt++ > 10000) break;
  HAL_I2C_Master_Transmit(&hi2c1,DEVICEADDR_OLED, screenBuffer,FRAMEBUFFER_START + (OLED_WIDTH * 2),1000);
}

void clear_screen(void) {
  memset(&screenBuffer[FRAMEBUFFER_START], 0, OLED_WIDTH * 2);
}
void set_screen(void) {
  memset(&screenBuffer[FRAMEBUFFER_START], 255, OLED_WIDTH * 2);
}

void draw_v_line(int16_t x, int16_t y, uint16_t h, uint8_t color){
  for(int i = 0; i <= h; i++){
    write_pixel(x, y+i, color);
  }
}

void write_pixel(int16_t x, int16_t y, uint8_t color){
  if(x>95 || y >15){
    return;
  }
  if(color == 1){
    screenBuffer[FRAMEBUFFER_START + (x + ((y/8)*96))] |=  (1 << y % 8);
  } else if (color == 0){
    screenBuffer[FRAMEBUFFER_START + (x + ((y/8)*96))] &= ~(1 << y % 8);
  }
}

#define CHAR_WIDTH 6
#define CHAR_HEIGHT 8
void draw_char(unsigned char c, uint8_t x, uint8_t y, uint8_t brightness) {
    c = c & 0x7F;
    if (c < ' ') {
        c = 0;
    } else {
        c -= ' ';
    }
    uint8_t * chr = (uint8_t *) font[c];
    for (uint8_t j=0; j<CHAR_WIDTH; j++) {
        for (uint8_t i=0; i<CHAR_HEIGHT; i++) {
            if (chr[j] & (1<<i)) {
                write_pixel(x+j, y+i, 1);
            } else {
                write_pixel(x+j, y+i, 0);
            }
        }
    }
}

void draw_string(const unsigned char* str, uint8_t x, uint8_t y, uint8_t brightness) {
    while (*str) {
        draw_char(*str++, x, y, brightness);
        x += CHAR_WIDTH;
    }
}

void SystemClock_Config(void)
{
  RCC_OscInitTypeDef RCC_OscInitStruct = {0};
  RCC_ClkInitTypeDef RCC_ClkInitStruct = {0};
  RCC_PeriphCLKInitTypeDef PeriphClkInit = {0};

  RCC_OscInitStruct.OscillatorType = RCC_OSCILLATORTYPE_HSI|RCC_OSCILLATORTYPE_HSI14
                              |RCC_OSCILLATORTYPE_HSI48;
  RCC_OscInitStruct.HSIState = RCC_HSI_ON;
  RCC_OscInitStruct.HSI48State = RCC_HSI48_ON;
  RCC_OscInitStruct.HSI14State = RCC_HSI14_ON;
  RCC_OscInitStruct.HSICalibrationValue = RCC_HSICALIBRATION_DEFAULT;
  RCC_OscInitStruct.HSI14CalibrationValue = 16;
  RCC_OscInitStruct.PLL.PLLState = RCC_PLL_ON;
  RCC_OscInitStruct.PLL.PLLSource = RCC_PLLSOURCE_HSI48;
  RCC_OscInitStruct.PLL.PLLMUL = RCC_PLL_MUL2;
  RCC_OscInitStruct.PLL.PREDIV = RCC_PREDIV_DIV2;
  HAL_RCC_OscConfig(&RCC_OscInitStruct);

  RCC_ClkInitStruct.ClockType = RCC_CLOCKTYPE_HCLK|RCC_CLOCKTYPE_SYSCLK
                              |RCC_CLOCKTYPE_PCLK1;
  RCC_ClkInitStruct.SYSCLKSource = RCC_SYSCLKSOURCE_PLLCLK;
  RCC_ClkInitStruct.AHBCLKDivider = RCC_SYSCLK_DIV1;
  RCC_ClkInitStruct.APB1CLKDivider = RCC_HCLK_DIV1;

  HAL_RCC_ClockConfig(&RCC_ClkInitStruct, FLASH_LATENCY_1);

  PeriphClkInit.PeriphClockSelection = RCC_PERIPHCLK_USB|RCC_PERIPHCLK_I2C1;
  PeriphClkInit.I2c1ClockSelection = RCC_I2C1CLKSOURCE_HSI;
  PeriphClkInit.UsbClockSelection = RCC_USBCLKSOURCE_HSI48;

  HAL_RCCEx_PeriphCLKConfig(&PeriphClkInit);
}

static void MX_ADC_Init(void)
{
  __HAL_RCC_DMA1_CLK_ENABLE();
  __HAL_RCC_ADC1_CLK_ENABLE();

  ADC_ChannelConfTypeDef sConfig = {0};

  hadc.Instance = ADC1;
  hadc.Init.ClockPrescaler = ADC_CLOCK_ASYNC_DIV1;
  hadc.Init.Resolution = ADC_RESOLUTION_12B;
  hadc.Init.DataAlign = ADC_DATAALIGN_RIGHT;
  hadc.Init.ScanConvMode = ADC_SCAN_DIRECTION_FORWARD;
  hadc.Init.EOCSelection = ADC_EOC_SEQ_CONV;
  hadc.Init.LowPowerAutoWait = DISABLE;
  hadc.Init.LowPowerAutoPowerOff = DISABLE;
  hadc.Init.ContinuousConvMode = DISABLE;
  hadc.Init.DiscontinuousConvMode = DISABLE;
  hadc.Init.ExternalTrigConv = ADC_EXTERNALTRIGCONV_T1_CC4;//ADC_EXTERNALTRIGCONV_T2_TRGO;
  hadc.Init.ExternalTrigConvEdge = ADC_EXTERNALTRIGCONVEDGE_RISING;
  hadc.Init.DMAContinuousRequests = ENABLE;
  hadc.Init.Overrun = ADC_OVR_DATA_PRESERVED;
  HAL_ADC_Init(&hadc);

  sConfig.Channel = ADC_CHANNEL_0;
  sConfig.Rank = ADC_RANK_CHANNEL_NUMBER;
  sConfig.SamplingTime = ADC_SAMPLETIME_71CYCLES_5;
  HAL_ADC_ConfigChannel(&hadc, &sConfig);

  sConfig.Channel = ADC_CHANNEL_1;
  HAL_ADC_ConfigChannel(&hadc, &sConfig);

  sConfig.Channel = ADC_CHANNEL_2;
  HAL_ADC_ConfigChannel(&hadc, &sConfig);

  sConfig.Channel = ADC_CHANNEL_5;
  HAL_ADC_ConfigChannel(&hadc, &sConfig);

  HAL_ADC_MspInit(&hadc);
}

static void MX_I2C1_Init(void)
{

  hi2c1.Instance = I2C1;
  hi2c1.Init.Timing = 0x2000090E;
  hi2c1.Init.OwnAddress1 = 0;
  hi2c1.Init.AddressingMode = I2C_ADDRESSINGMODE_7BIT;
  hi2c1.Init.DualAddressMode = I2C_DUALADDRESS_DISABLE;
  hi2c1.Init.OwnAddress2 = 0;
  hi2c1.Init.OwnAddress2Masks = I2C_OA2_NOMASK;
  hi2c1.Init.GeneralCallMode = I2C_GENERALCALL_DISABLE;
  hi2c1.Init.NoStretchMode = I2C_NOSTRETCH_DISABLE;
  HAL_I2C_Init(&hi2c1);

  HAL_I2CEx_ConfigAnalogFilter(&hi2c1, I2C_ANALOGFILTER_ENABLE);

  HAL_I2CEx_ConfigDigitalFilter(&hi2c1, 0);
}

static void MX_I2C2_Init(void)
{

  hi2c2.Instance = I2C2;
  hi2c2.Init.Timing = 0x20303E5D;
  hi2c2.Init.OwnAddress1 = 0;
  hi2c2.Init.AddressingMode = I2C_ADDRESSINGMODE_7BIT;
  hi2c2.Init.DualAddressMode = I2C_DUALADDRESS_DISABLE;
  hi2c2.Init.OwnAddress2 = 0;
  hi2c2.Init.OwnAddress2Masks = I2C_OA2_NOMASK;
  hi2c2.Init.GeneralCallMode = I2C_GENERALCALL_DISABLE;
  hi2c2.Init.NoStretchMode = I2C_NOSTRETCH_DISABLE;
  HAL_I2C_Init(&hi2c2);

  HAL_I2CEx_ConfigAnalogFilter(&hi2c2, I2C_ANALOGFILTER_ENABLE);

  HAL_I2CEx_ConfigDigitalFilter(&hi2c2, 0);
}

static void MX_IWDG_Init(void)
{
  hiwdg.Instance = IWDG;
  hiwdg.Init.Prescaler = IWDG_PRESCALER_4;
  hiwdg.Init.Window = 4095;
  hiwdg.Init.Reload = 4095;
  HAL_IWDG_Init(&hiwdg);
}

static void TIM3_Init(void)
{
  __HAL_RCC_TIM3_CLK_ENABLE();
  TIM_ClockConfigTypeDef sClockSourceConfig = {0};

  /*
       + Period = 10000 - 1
       + Prescaler = ((8000000/2)/10000) - 1

  */
  htim3.Instance = TIM3;
  htim3.Init.Period = (CDC_POLLING_INTERVAL*1000) - 1;
  htim3.Init.Prescaler = 399;
  htim3.Init.ClockDivision = 0;
  htim3.Init.CounterMode = TIM_COUNTERMODE_UP;
  htim3.Init.AutoReloadPreload = TIM_AUTORELOAD_PRELOAD_DISABLE;
  if(HAL_TIM_Base_Init(&htim3) != HAL_OK)
  {
    /* Initialization Error */
    Error_Handler();
  }
  sClockSourceConfig.ClockSource = TIM_CLOCKSOURCE_INTERNAL;
  HAL_TIM_ConfigClockSource(&htim3, &sClockSourceConfig);
}

static void MX_TIM1_Init(void)
{

  __HAL_RCC_TIM1_CLK_ENABLE();

  TIM_ClockConfigTypeDef sClockSourceConfig = {0};
  TIM_MasterConfigTypeDef sMasterConfig = {0};
  TIM_OC_InitTypeDef sConfigOC = {0};
  TIM_BreakDeadTimeConfigTypeDef sBreakDeadTimeConfig = {0};

  htim1.Instance = TIM1;
  htim1.Init.Prescaler = 2048; // 2048
  htim1.Init.CounterMode = TIM_COUNTERMODE_UP;
  htim1.Init.Period = 4096; // 4096
  htim1.Init.ClockDivision = TIM_CLOCKDIVISION_DIV4;
  htim1.Init.RepetitionCounter = 0;
  htim1.Init.AutoReloadPreload = TIM_AUTORELOAD_PRELOAD_ENABLE;
  HAL_TIM_Base_Init(&htim1);

  sClockSourceConfig.ClockSource = TIM_CLOCKSOURCE_INTERNAL;
  HAL_TIM_ConfigClockSource(&htim1, &sClockSourceConfig);

  HAL_TIM_PWM_Init(&htim1);
  HAL_TIM_OC_Init(&htim1);

  sMasterConfig.MasterOutputTrigger = TIM_TRGO_RESET;
  sMasterConfig.MasterSlaveMode = TIM_MASTERSLAVEMODE_DISABLE;
  HAL_TIMEx_MasterConfigSynchronization(&htim1, &sMasterConfig);

  sConfigOC.OCMode = TIM_OCMODE_PWM1;
  sConfigOC.Pulse = 50;
  sConfigOC.OCPolarity = TIM_OCPOLARITY_HIGH;
  sConfigOC.OCNPolarity = TIM_OCNPOLARITY_HIGH;
  sConfigOC.OCFastMode = TIM_OCFAST_DISABLE;
  sConfigOC.OCIdleState = TIM_OCIDLESTATE_RESET;
  sConfigOC.OCNIdleState = TIM_OCNIDLESTATE_RESET;
  HAL_TIM_PWM_ConfigChannel(&htim1, &sConfigOC, TIM_CHANNEL_1);

  sConfigOC.OCMode = TIM_OCMODE_PWM2;
  sConfigOC.Pulse = 4050;
  HAL_TIM_OC_ConfigChannel(&htim1, &sConfigOC, TIM_CHANNEL_4);

  sBreakDeadTimeConfig.OffStateRunMode = TIM_OSSR_DISABLE;
  sBreakDeadTimeConfig.OffStateIDLEMode = TIM_OSSI_DISABLE;
  sBreakDeadTimeConfig.LockLevel = TIM_LOCKLEVEL_OFF;
  sBreakDeadTimeConfig.DeadTime = 0;
  sBreakDeadTimeConfig.BreakState = TIM_BREAK_DISABLE;
  sBreakDeadTimeConfig.BreakPolarity = TIM_BREAKPOLARITY_HIGH;
  sBreakDeadTimeConfig.AutomaticOutput = TIM_AUTOMATICOUTPUT_DISABLE;
  HAL_TIMEx_ConfigBreakDeadTime(&htim1, &sBreakDeadTimeConfig);

  HAL_TIM_MspPostInit(&htim1);
}
/*
static void MX_TIM2_Init(void)
{
  TIM_ClockConfigTypeDef sClockSourceConfig = {0};
  TIM_MasterConfigTypeDef sMasterConfig = {0};
  TIM_OC_InitTypeDef sConfigOC = {0};

  htim2.Instance = TIM2;
  htim2.Init.Prescaler = 2096;
  htim2.Init.CounterMode = TIM_COUNTERMODE_UP;
  htim2.Init.Period = 4096;
  htim2.Init.ClockDivision = TIM_CLOCKDIVISION_DIV4;
  htim2.Init.AutoReloadPreload = TIM_AUTORELOAD_PRELOAD_ENABLE;
  HAL_TIM_PWM_Init(&htim2);

  sClockSourceConfig.ClockSource = TIM_CLOCKSOURCE_INTERNAL;
  HAL_TIM_ConfigClockSource(&htim2, &sClockSourceConfig);

  sMasterConfig.MasterOutputTrigger = TIM_TRGO_UPDATE;
  sMasterConfig.MasterSlaveMode = TIM_MASTERSLAVEMODE_DISABLE;
  HAL_TIMEx_MasterConfigSynchronization(&htim2, &sMasterConfig);

  sConfigOC.OCMode = TIM_OCMODE_PWM1;
  sConfigOC.Pulse = 30;
  sConfigOC.OCPolarity = TIM_OCPOLARITY_HIGH;
  sConfigOC.OCFastMode = TIM_OCFAST_DISABLE;
  HAL_TIM_PWM_ConfigChannel(&htim2, &sConfigOC, TIM_CHANNEL_2);

  HAL_TIM_MspPostInit(&htim2);

}
*/

static void MX_DMA_Init(void)
{
  __HAL_RCC_DMA1_CLK_ENABLE();

  HAL_NVIC_SetPriority(DMA1_Channel1_IRQn, 0, 0);
  HAL_NVIC_EnableIRQ(DMA1_Channel1_IRQn);

  HAL_NVIC_SetPriority(TIM3_IRQn, 0, 0);
  HAL_NVIC_EnableIRQ(TIM3_IRQn);
  /*
  HAL_NVIC_SetPriority(DMA1_Channel2_3_IRQn, 0, 0);
  HAL_NVIC_EnableIRQ(DMA1_Channel2_3_IRQn);
  HAL_NVIC_SetPriority(DMA1_Channel4_5_6_7_IRQn, 0, 0);
  HAL_NVIC_EnableIRQ(DMA1_Channel4_5_6_7_IRQn);
  */

}

static void MX_GPIO_Init(void)
{
  GPIO_InitTypeDef GPIO_InitStruct = {0};

  __HAL_RCC_GPIOA_CLK_ENABLE();
  __HAL_RCC_GPIOB_CLK_ENABLE();
  __HAL_RCC_GPIOC_CLK_ENABLE();

  GPIO_InitStruct.Pin = B1_Pin|B2_Pin;
  GPIO_InitStruct.Mode = GPIO_MODE_INPUT;
  GPIO_InitStruct.Pull = GPIO_PULLDOWN;
  HAL_GPIO_Init(GPIOA, &GPIO_InitStruct);

  GPIO_InitStruct.Pin = B1_1_Pin;
  GPIO_InitStruct.Mode = GPIO_MODE_INPUT;
  GPIO_InitStruct.Pull = GPIO_PULLDOWN;
  HAL_GPIO_Init(GPIOC, &GPIO_InitStruct);



  GPIO_InitStruct.Pin = INT_N_Pin;
  GPIO_InitStruct.Mode = GPIO_MODE_INPUT;
  GPIO_InitStruct.Pull = GPIO_NOPULL;
  HAL_GPIO_Init(INT_N_GPIO_Port, &GPIO_InitStruct);

}

void Error_Handler(void)
{

}

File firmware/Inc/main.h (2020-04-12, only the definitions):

#define IIN_Pin GPIO_PIN_0
#define IIN_GPIO_Port GPIOA
#define TTIP_Pin GPIO_PIN_1
#define TTIP_GPIO_Port GPIOA
#define UIN_Pin GPIO_PIN_2
#define UIN_GPIO_Port GPIOA
#define B1_Pin GPIO_PIN_3
#define B1_GPIO_Port GPIOA
#define B1_1_Pin GPIO_PIN_13
#define B1_1_GPIO_Port GPIOC
#define B2_Pin GPIO_PIN_4
#define B2_GPIO_Port GPIOA
#define TREF_Pin GPIO_PIN_5
#define TREF_GPIO_Port GPIOA
#define STUSB_SCL_Pin GPIO_PIN_10
#define STUSB_SCL_GPIO_Port GPIOB
#define STUSB_SDA_Pin GPIO_PIN_11
#define STUSB_SDA_GPIO_Port GPIOB
#define INT_N_Pin GPIO_PIN_12
#define INT_N_GPIO_Port GPIOB
#define PWMOUT_Pin GPIO_PIN_8
#define PWMOUT_GPIO_Port GPIOA
#define OLED_SCL_Pin GPIO_PIN_6
#define OLED_SCL_GPIO_Port GPIOB
#define OLED_SDA_Pin GPIO_PIN_7
#define OLED_SDA_GPIO_Port GPIOB

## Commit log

2018-11-08 added kicad files
    [TS100C.kicad_pcb, TS100C.sch]
2018-11-08 added most parts
    [TS100C.kicad_pcb, TS100C.sch]
2018-11-08 update PCB
    [TS100C.kicad_pcb, TS100C.sch]
2018-11-09 finalized PCB
    [TS100C.kicad_pcb]
2018-11-09 fixed connector error
    [TS100C.kicad_pcb, TS100C.sch]
2018-12-04 updated files
    [TS100C-B.Cu.gbl, TS100C-B.Mask.gbs, TS100C-B.Paste.gbp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]
2018-12-09 file cleanup
    [TS100C.kicad_pcb, TS100C.sch]
2018-12-09 moved files
    [TS100C.kicad_pcb, TS100C.sch]
2019-05-22 removed gerber
    [TS100C-B.Cu.gbl, TS100C-B.Mask.gbs, TS100C-B.Paste.gbp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]
2019-05-22 added new gerber
    [TS100C-B_Cu.gbl, TS100C-B_Mask.gbs, TS100C-B_Paste.gbp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]
2019-05-22 updated PCB+schematic to STUSB4500
    [TS100C.kicad_pcb, TS100C.sch]
2019-05-22 added silkscreen
    [TS100C-B_Cu.gbl, TS100C-B_Mask.gbs, TS100C-B_Paste.gbp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]
2019-07-16 updated pcb
    [TS100C-B_Cu.gbl, TS100C-B_Mask.gbs, TS100C-B_Paste.gbp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]
2019-07-24 updated hardware
    [TS100C-B_Cu.gbl, TS100C-B_Mask.gbs, TS100C-B_Paste.gbp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]
2019-07-24 added todos
    [TS100C.kicad_pcb, TS100C.sch]
2019-08-13 fixed bom
    [TS100C-B_Cu.gbl, TS100C-B_Mask.gbs, TS100C-B_Paste.gbp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]
2019-08-13 optimized bom
    [TS100C.sch]
2019-08-21 optimized values
    [TS100C.kicad_pcb, TS100C.sch]
2019-08-29 TIM1 PWM + ADC Trigger -> DMA works
2019-09-03 added BOM
    [TS100C.csv, TS100C.sch]
2019-12-17 fixed STM
    [TS100C.csv, TS100C.kicad_pcb, TS100C.sch]
2019-12-23 production files
    [BOM.csv, TS100C.kicad_pcb, TS100C.sch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]
2019-12-24 Make a kitspace compatible bom
    Delete some rows/columns from production/BOM.csv
    [kitspace_bom.csv]
2019-12-31 updated kitspace bom
    [kitspace_bom.csv]
2019-12-31 updated bom
    [kitspace_bom.csv]
2020-01-03 updated cap values
    [BOM.csv, TS100C.sch, kitspace_bom.csv]
2020-01-15 updated DFU screen, TS100 stores now set-temp, highly improved temperature control
2020-01-15 fixed power-bar bug
2020-01-21 optimized TC & Display connector, added pullup
    [TS100C.kicad_pcb, TS100C.sch]
2020-01-28 fixed cpl file bugs
    [POS-TOP-X2.csv]
2020-02-04 fixed initial temp set
    [main.c]
2020-02-10 Upadeted BOM.csv with Farnell#
    Added Farnell ordering numbers for non-LCSC parts
    [BOM.csv]
2020-02-10 merged boms
    [kitspace_bom.csv]
2020-03-01 added C245_Test
    [C245.kicad_pcb, C245.sch]
2020-03-01 finished routing C245_Test
    [C245.kicad_pcb]
2020-03-01 finalized design
    [C245.kicad_pcb]
2020-03-01 added connector pcb, added Gerber
    [C245-B_Cu.gbl, C245-B_Mask.gbs, C245-B_Paste.gbp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]
2020-03-01 added connector, renamed files
    [C245_conn-B_Cu.gbl, C245_conn-B_Mask.gbs, C245_conn-B_Paste.gbp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]
2020-03-01 renamed files
    [C245-B_Cu.gbl, C245-B_Mask.gbs, C245-B_Paste.gbp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]
2020-03-01 moved folder
    [C245_conn-B_Cu.gbl, C245_conn-B_Mask.gbs, C245_conn-B_Paste.gbp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]
2020-03-01 added gerber zip
2020-03-20 removed old files
    [OtterIron_Devkit.kicad_pcb, OtterIron_Devkit.sch, USB Type C Port (SMD Type).STEP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]
2020-04-12 added current monitoring and current control, added devkit fw
2020-04-13 updated production files
    [BOM.csv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]
2020-04-15 moved files to new repo
    [BOM.csv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]
2020-04-17 added pdf
    [combined.GKO, combined.drl, combined.gbl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]
2020-06-23 fix BOM link
2020-10-26 added 12V and 9V profile
2022-01-09 hw v2.4 released
    [TS100C-B_Cu.gbl, TS100C-B_Mask.gbs, TS100C-B_Paste.gbp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]

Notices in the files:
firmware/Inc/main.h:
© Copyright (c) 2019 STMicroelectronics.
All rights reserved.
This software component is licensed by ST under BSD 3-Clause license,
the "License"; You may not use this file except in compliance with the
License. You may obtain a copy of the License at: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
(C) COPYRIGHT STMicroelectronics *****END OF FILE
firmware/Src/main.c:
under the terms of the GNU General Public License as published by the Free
